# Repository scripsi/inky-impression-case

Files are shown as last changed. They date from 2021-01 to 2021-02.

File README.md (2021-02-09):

# Inky Impression Case

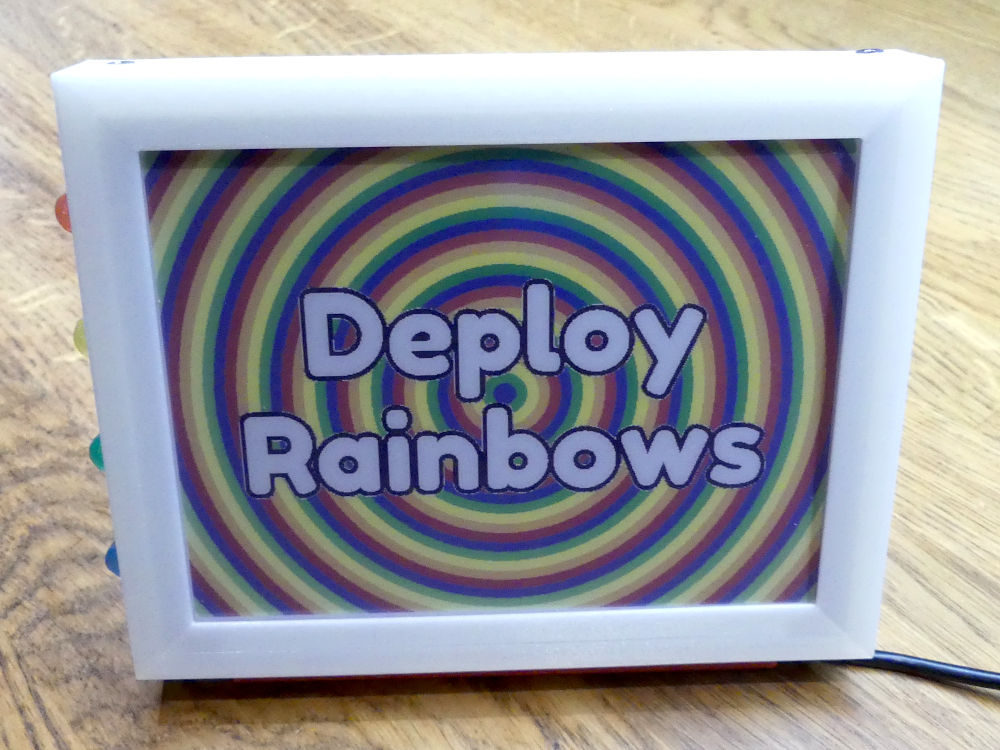
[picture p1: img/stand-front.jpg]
Case on stand - Front

## Introduction

This is a wall-mounting or desk-stand case for the [Pimoroni Inky Impression](https://shop.pimoroni.com/products/inky-impression) 7-colour e-ink display. I wanted to make a simple protective case for the display and a Raspberry Pi Zero W which had the following features:

* A clean front with no visible fixings and a symmetrical border around the image area
* No pressure applied to the fragile glass screen of the Inky Impression
* Access to the 4 buttons on the Inky Impression board
* Access to the breakout connector on the Inky Impression board
* Simple wall-mounting
* An optional desk-stand

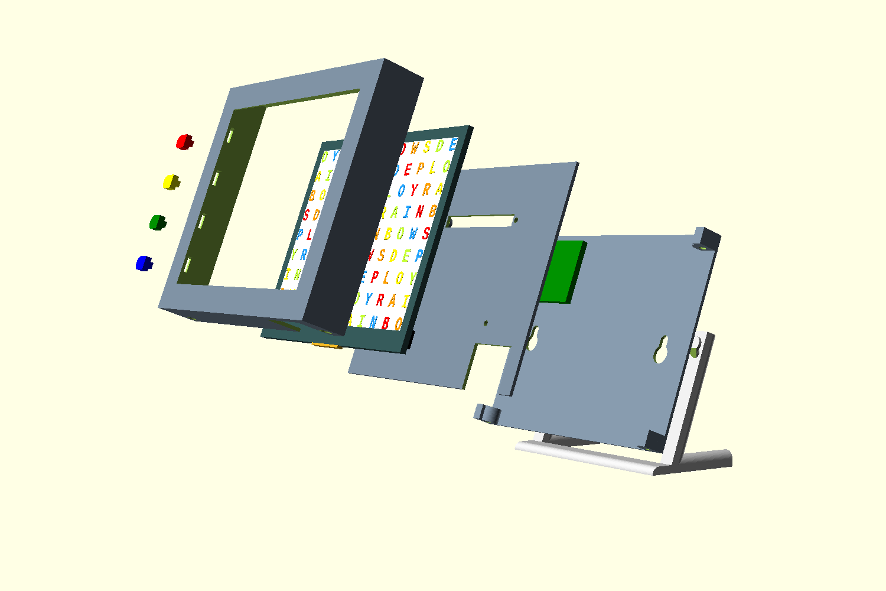
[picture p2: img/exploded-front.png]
Exploded Front View


The Inky Impression only has mounting points on the back surface, which makes it hard to produce a standard, 3d-printable case that doesn't put any pressure on the fragile glass front. Pressing it into a frame or sliding it into slots might put too much strain on some areas. I solved this by adding a backplane within the case, which screws to the Inky Impression's mount points and holds it slightly away from the front of the case.

Side-mounted buttons are also held in position by the backplane and help activate the switches on the Inky Impression board when it is in the case. The rear panel has keyholes for wall-mounting on screws, and is held onto the front of the case by 4 bolts (with optional threaded inserts). The case has a cutout at the bottom for access to the breakout connector and as a cable-exit for the Raspberry Pi's power cable.

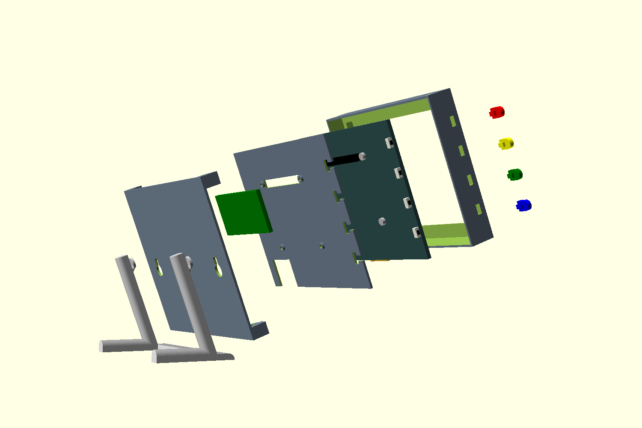
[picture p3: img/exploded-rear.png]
Exploded Rear View


## Printing

Print the following parts:

* 1 x inky-impression-case-frame.stl
* 1 x inky-impression-case-backplane.stl
* 4 x inky-impression-case-button.stl

And, depending on whether or not you are using threaded inserts, either:

* 1 x inky-impression-case-rearpanel.stl (with inserts)

or:

* 1 x inky-impression-case-rearpanel-no-inserts.stl (without inserts)

There is also an optional stand that clips into the keyholes on the rear panel:

* [OPTIONAL: 1 x inky-impression-case-stand.stl]

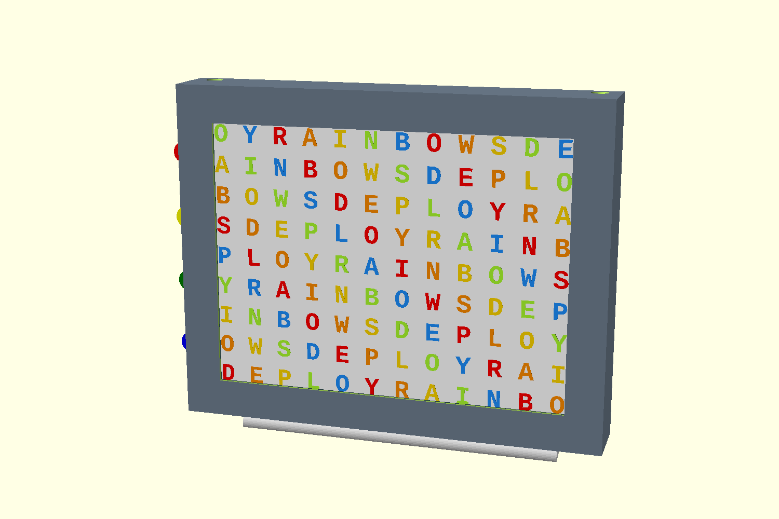
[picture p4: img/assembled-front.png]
Front View


The design is optimised for a 0.4mm nozzle and 0.2mm layer height with 20% infill. Using a concentric pattern on the bottom layer gives a nice finish to the frame.

You will also need:

* 4 x M2.5 bolts, 6mm long (you can use the ones supplied with the Inky Impression)
* 4 x M2.5 countersunk bolts, 6mm long
* [OPTIONAL: 4 x M2.5 threaded inserts - brass heat-set type, external diameter 3.5mm, length 4-6mm]

## Construction

1. Test that the backplane fits right down into the frame to rest on the ledges around the top and sides. It should be a really snug fit - sandpaper the edges of the backplane a bit if it won't go in on the first try!
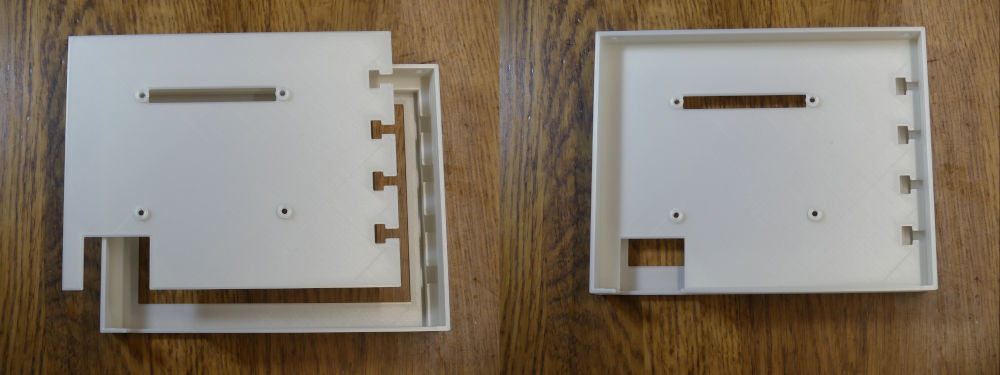
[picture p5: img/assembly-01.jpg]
Assembly - stage 1

2. Mount the backplane to the Inky Impression using the M2.5 bolts that are supplied with the display.
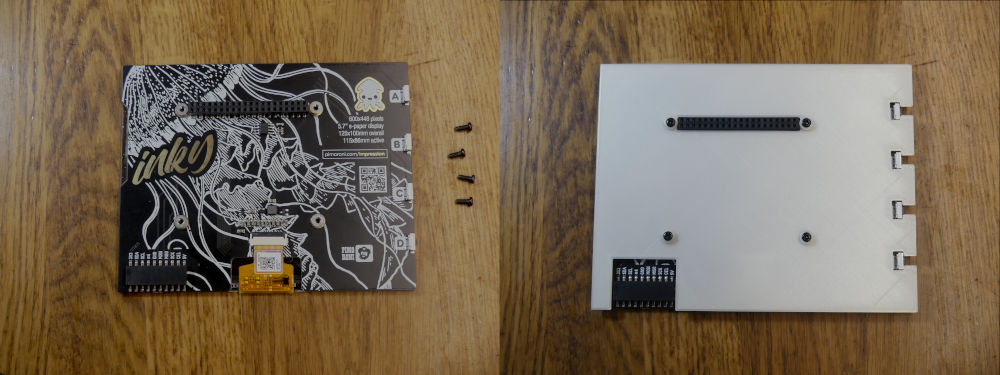
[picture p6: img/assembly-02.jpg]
Assembly - stage 2

3. Lay the frame face down on a worksurface and slide the four buttons into the slots in the side, with the rectangular lugs on each button facing towards you.
4. Gently slide the Inky Impression on its backplane into the frame, with the screen facing down and the slots for the buttons on the correct side.
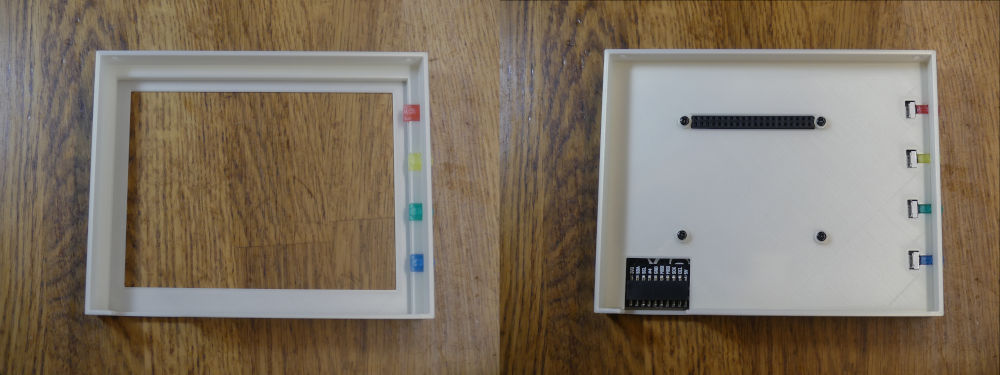
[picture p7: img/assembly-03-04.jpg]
Assembly - stages 3 and 4

5. Carefully press the Raspberry Pi Zero onto the header on the Inky Impression so that it is held firmly in place. Attach a Micro USB cable to the connector nearest the corner of the Pi and lead the cable through the slot in the bottom of the frame.
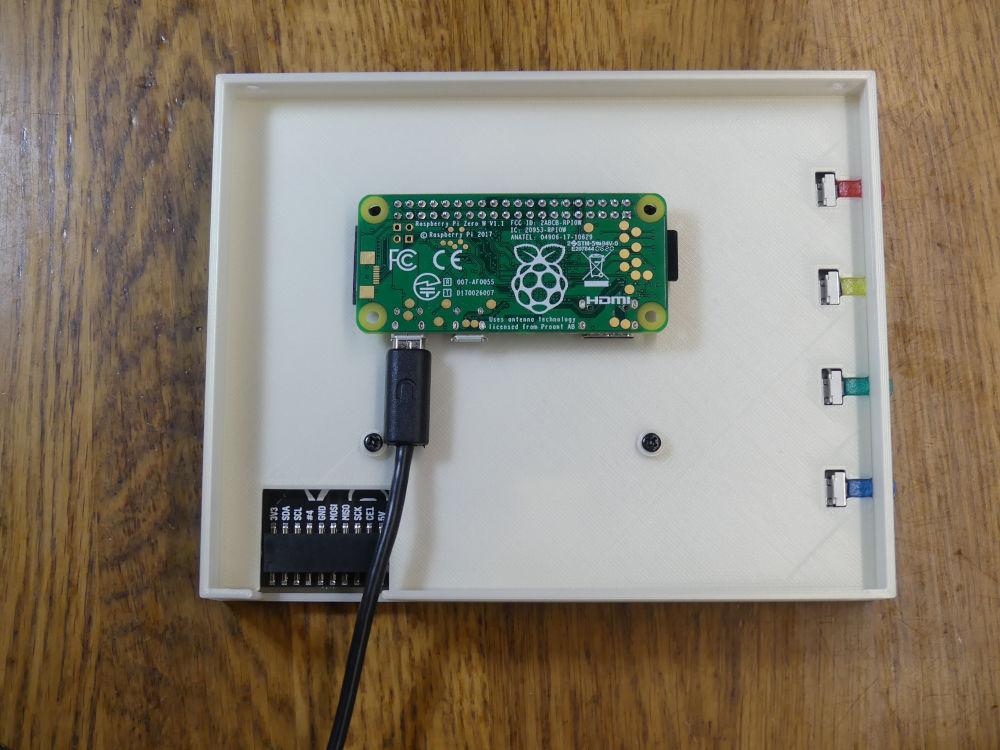
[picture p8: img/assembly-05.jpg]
Assembly - stage 5

6. [Heat-set the inserts](https://markforged.com/resources/blog/heat-set-inserts) (if using) into the mounts on the rear panel.
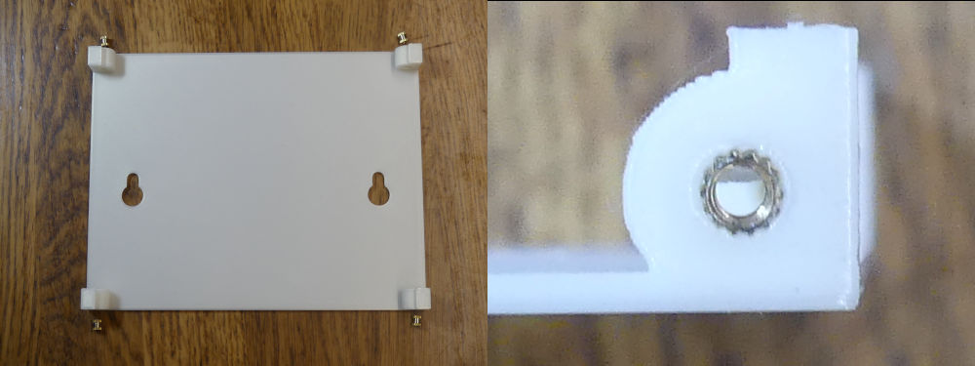
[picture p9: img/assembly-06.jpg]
Assembly - stage 6

7. Place the rear panel into the frame. The pads on the rear panel mounts should hold the backplane in place within the case. Use the M2.5 countersunk bolts to secure the rear panel to the case.
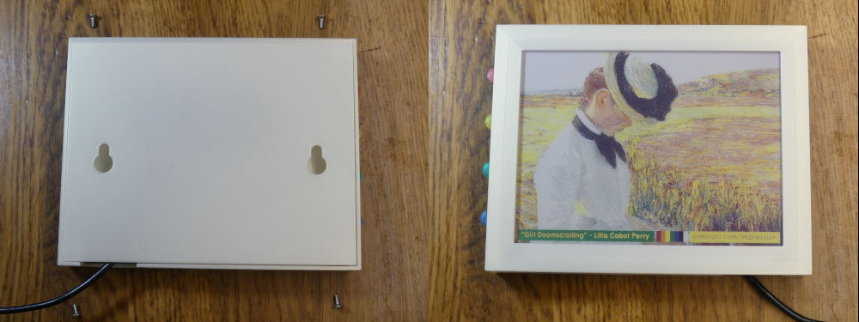
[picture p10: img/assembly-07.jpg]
Assembly - stage 7

8. To wall-mount, place two screws on the wall, 100mm apart and horizontally in line with where you want the centre of the screen, then slot the keyholes in the rear panel onto the screws.

## Customisation

I have included the OpenScad file for the design. It has some basic parameters that allow you to change the size and type of the fixing bolts for the case. Read the comments in the file to see how to use it.

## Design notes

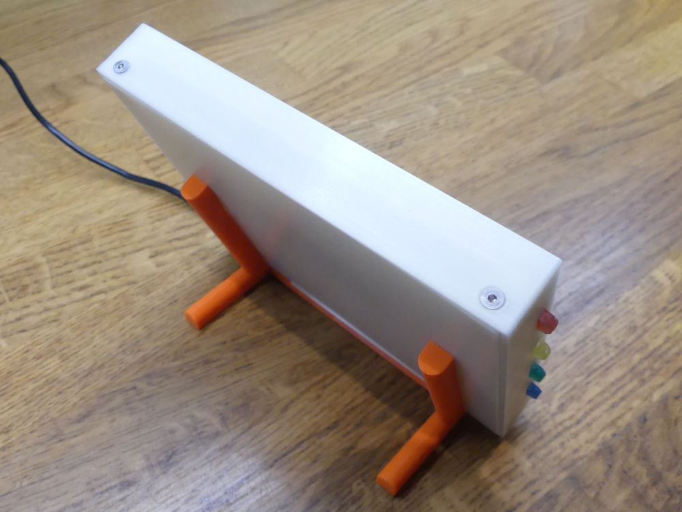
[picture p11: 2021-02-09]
img/stand-rear.jpg

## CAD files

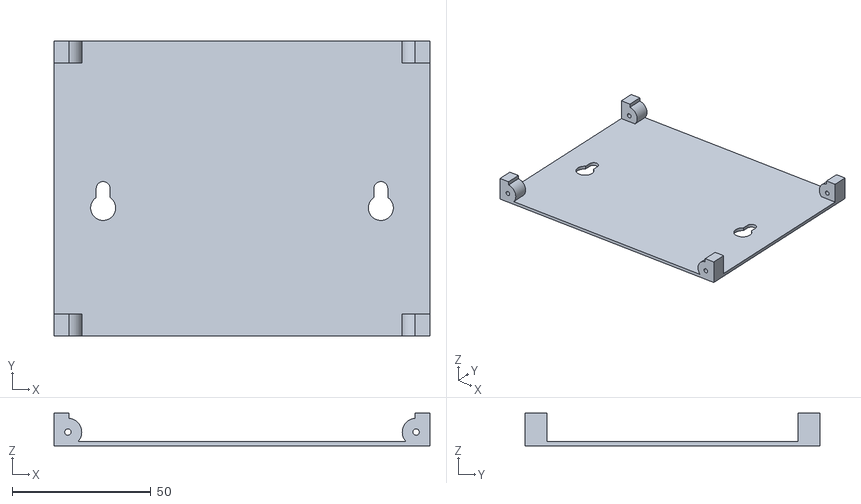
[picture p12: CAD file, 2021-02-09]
inky-impression-case-rearpanel-no-inserts.stl
135.4 x 106.4 x 11.8

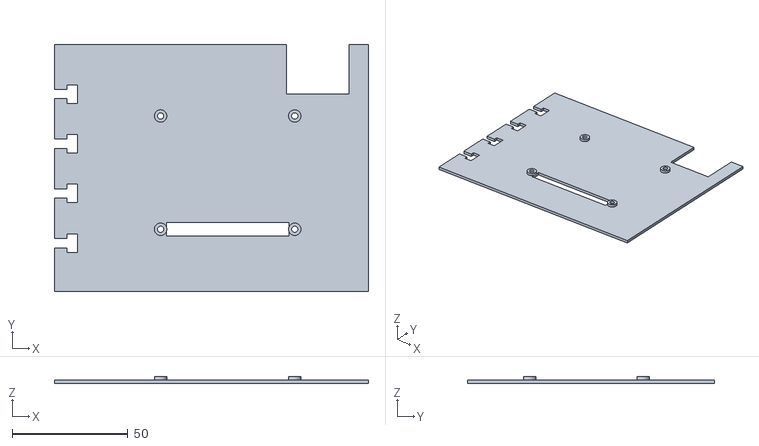
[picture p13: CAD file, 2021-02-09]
inky-impression-case-backplane.stl
135.8 x 106.8 x 3.10

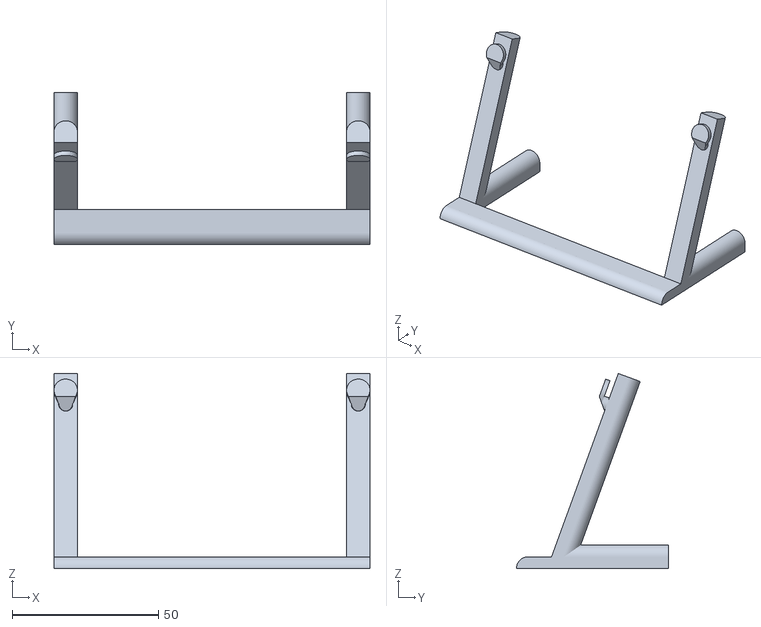
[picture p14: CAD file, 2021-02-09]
inky-impression-case-stand.stl
108.0 x 52.0 x 66.6

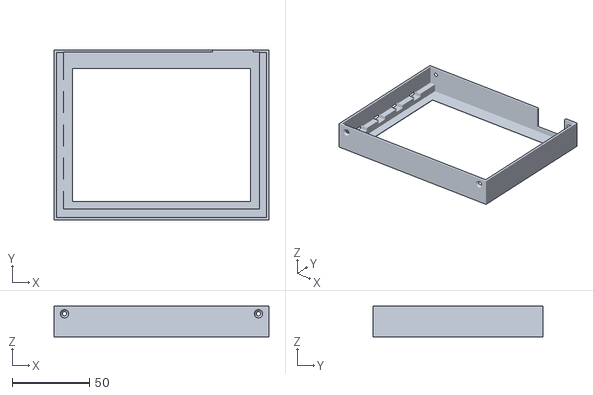
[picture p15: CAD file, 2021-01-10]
inky-impression-case-frame.stl
139.0 x 110.0 x 20.0

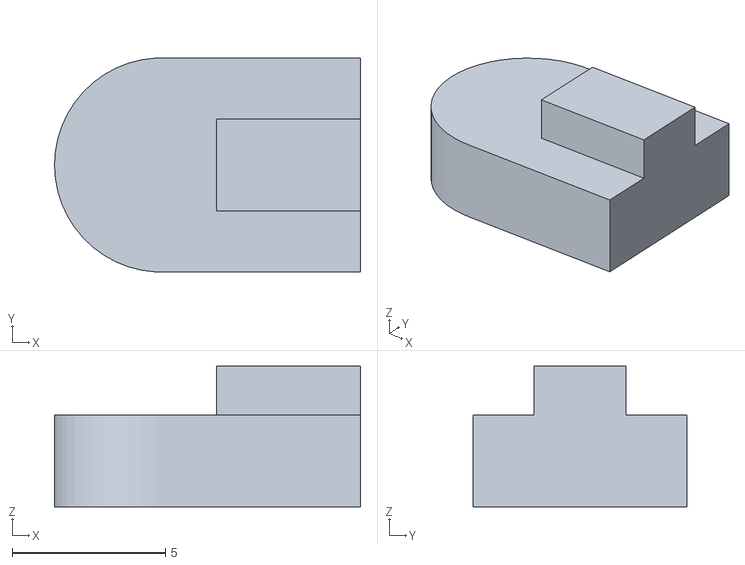
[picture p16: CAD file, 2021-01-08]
inky-impression-case-button.stl
10.0 x 7.00 x 4.60

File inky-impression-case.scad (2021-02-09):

// inky-impression-case.scad
//
// Copyright: Douglas Reed, January 2021
//
// This is a wall-mounting case for:
//
//   Pimoroni Inky Impression 7-colour e-ink display
//   https://shop.pimoroni.com/products/inky-impression
//
// See accompanying readme.md for full details

// The case consists of the following parts:
//
//   1 x FRAME - The front and sides of the case
//   1 x REARPANEL - The rear panel and wall-mount
//   1 x BACKPLANE - An internal panel to hold the Inky Impression in position
//   4 x BUTTON - Button extensions to allow operation of the Inky Impression's
//                buttons
//
// There is also an optional addition:
//
//   1 x STAND - A desk stand that clips into the wall-mount keyholes
//               on the rear panel

// Use the customizer in OpenScad (Menu: Window -> Customizer) to set the
// following parameters and show different parts or views of the model. Only set
// one of these to "true" at a time, and keep the others "false"!

// The frame in printable orientation.
FRAME = false;

// The backplane in printable orientation.
BACKPLANE = false;

// The rear panel in printable orientation.
REARPANEL = false;

// A button in printable orientation
BUTTON = false;

// A desk stand in printable orientation
STAND = false;

// Show the fully assembled case
ASSEMBLED = false;

// Show an exploded view of the case
EXPLODED = false;

// The rear panel is held on by fixing bolts. Set the following parameters 
// According to the bolts you are using

// The diameter of the rear panel fixing bolts
BOLT_DIAMETER = 2.5; // M2.5 bolts

// Countersunk fixing bolts
BOLT_COUNTERSUNK = true;

// The rear panel mounts can take heat-set threaded inserts to make it easier to
// screw in the bolts. Set the following parameter to the recommended hole
// diameter for the inserts you are using (max: 6). If you don't want to
// use inserts and just want to self-tap the bolts into the plastic, set
// this to slightly less than the diameter of the bolts you are using,
// for example: 2.3 for M2.5 bolts

// Threaded insert outer diameter
INSERT_DIAMETER = 3.5;

// Other editable parameters are at the end of the file!

// *** MAIN ROUTINE ***

if (ASSEMBLED) {
  // shows the case fully assembled with Inky Impression and Raspberry Pi Zero
  // boards in position. Prefix any of the lines below with "*" to temporarily
  // remove that element and see inside the case
  frame();
  rearpanel();
  backplane();
  buttons();
  stand();
  inky();
  rpizero();
} else
if (EXPLODED) {
  rotate([-stand_angle,0,0]) {
    translate([0,-50,0]) frame();
    translate([0,130,0]) rearpanel();
    translate([0,150,0]) stand();
    translate([0,50,0]) backplane();
    translate([-50,-50,0]) buttons();
    inky();
    translate([0,80,0]) rpizero();
  }
} else {
  // shows case parts in the correct orientation for printing
  if (FRAME) { rotate([90,0,0]) frame(); }
  if (REARPANEL) { rotate([-90,0,0]) rearpanel(); }
  if (BACKPLANE) { rotate([90,0,0]) backplane(); }
  if (BUTTON) { rotate([90,0,0]) button(0); }
  if (STAND) { rotate([-stand_angle,0,0]) stand(); }
}


// *** MODULES ***

module frame() {
  // The front and sides of the case
  difference() {
    union() { // union of solids
      translate([frame_offset_w,frame_offset_d,frame_offset_h])
        color("SlateGray") cube([frame_w,frame_d,frame_h]);
    } // union of solids
    
    union() { // union of holes
      // screen cutout
      translate([inky_screen_offset_w, frame_offset_d - a_bit, inky_screen_offset_h])
        cube([inky_screen_w, frame_thickness_front + a_bit_more, inky_screen_h]);
      // inky board cutout
      translate([-frame_clearance_w, frame_offset_d + frame_thickness_front, -inky_screen_cable_h - frame_clearance_h])
        cube([inky_board_w + frame_clearance_w * 2, frame_d, inky_board_h+inky_screen_cable_h + frame_clearance_h]);
      // backplane ledge cutout
      translate([frame_offset_w + frame_thickness_sides, backplane_offset_d, frame_offset_h+frame_thickness_sides])
        cube([frame_w - (frame_thickness_sides * 2), frame_d, frame_h - (frame_thickness_sides * 2)]);

      // inky connector cutout
      translate([inky_conn_offset_w, inky_board_d, frame_offset_h - a_bit])
        cube([inky_conn_w, frame_d, frame_thickness_sides + a_bit_more]);
      
      // mount holes
      translate([rearpanel_offset_w, rearpanel_offset_d - rearpanel_mount_d, frame_offset_h]) {
        translate([rearpanel_mount_r,rearpanel_mount_d-rearpanel_mount_r+rearpanel_d,-a_bit]) bolt(radius=rearpanel_mount_bolt_r + rearpanel_mount_bolt_clearance,length=rearpanel_mount_bolt_length);
      }
      translate([rearpanel_offset_w + rearpanel_w - rearpanel_mount_w, rearpanel_offset_d - rearpanel_mount_d, frame_offset_h]) {
        translate([rearpanel_mount_w-rearpanel_mount_r,rearpanel_mount_d-rearpanel_mount_r+rearpanel_d,-a_bit]) bolt(radius=rearpanel_mount_bolt_r + rearpanel_mount_bolt_clearance,length=rearpanel_mount_bolt_length);
      }
      translate([rearpanel_offset_w + rearpanel_w - rearpanel_mount_w, rearpanel_offset_d - rearpanel_mount_d, frame_offset_h + frame_h]) {
        translate([rearpanel_mount_w-rearpanel_mount_r,rearpanel_mount_d-rearpanel_mount_r+rearpanel_d,a_bit]) rotate([180,0,0]) bolt(radius=rearpanel_mount_bolt_r + rearpanel_mount_bolt_clearance,length=rearpanel_mount_bolt_length);
      }
      translate([rearpanel_offset_w, rearpanel_offset_d - rearpanel_mount_d, frame_offset_h + frame_h]) {
        translate([rearpanel_mount_r,rearpanel_mount_d-rearpanel_mount_r+rearpanel_d,a_bit]) rotate([180,0,0]) bolt(radius=rearpanel_mount_bolt_r + rearpanel_mount_bolt_clearance,length=rearpanel_mount_bolt_length);
      }
      
      // buttons
      translate([-frame_border - a_bit, inky_board_d, inky_btn_a_offset_h - button_clearance])
        cube([frame_border + a_bit_more, button_d + button_clearance * 2 , button_h + button_clearance * 2]);
      translate([-frame_border - a_bit, inky_board_d, inky_btn_b_offset_h - button_clearance])
        cube([frame_border + a_bit_more, button_d + button_clearance * 2 , button_h + button_clearance * 2]);
      translate([-frame_border - a_bit, inky_board_d, inky_btn_c_offset_h - button_clearance])
        cube([frame_border + a_bit_more, button_d + button_clearance * 2 , button_h + button_clearance * 2]);
      translate([-frame_border - a_bit, inky_board_d, inky_btn_d_offset_h - button_clearance])
        cube([frame_border + a_bit_more, button_d + button_clearance * 2 , button_h + button_clearance * 2]);
    } // union of holes
  }
} // module frame()
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

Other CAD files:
inky-impression-case-rearpanel.stl

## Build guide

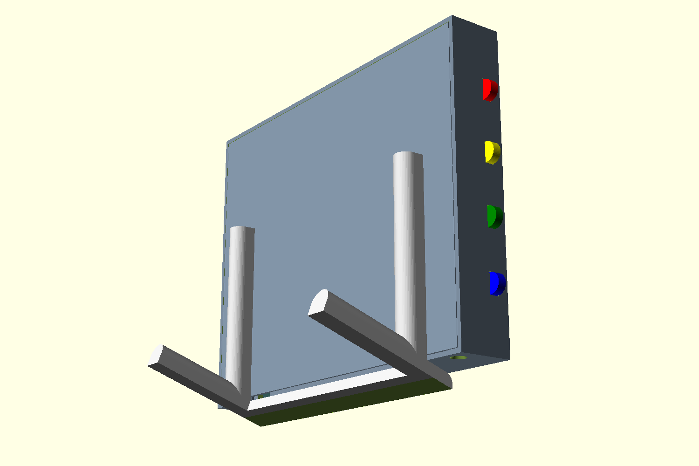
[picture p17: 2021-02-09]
img/assembled-rear.png

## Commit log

2021-01-07 added gitignore to leave out 3mf files
    [inky-impression-case-rearpanel.3mf]
2021-01-07 added version of rearpanel without inserts
    [inky-impression-case-backplane-no-inserts.stl, inky-impression-case-backplane.stl, inky-impression-case-button.stl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]
2021-01-07 fixed filenames
    [inky-impression-case-backplane-no-inserts.stl, inky-impression-case-rearpanel-no-inserts.stl, inky-impression-case-rearpanel.stl]
2021-01-08 Added images and build script
    [inky-impression-case-backplane.stl, inky-impression-case-button.stl, inky-impression-case-frame.stl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]
2021-01-08 Added exploded views
    [inky-impression-case-backplane.stl, inky-impression-case-frame.stl, inky-impression-case-rearpanel-no-inserts.stl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]
2021-01-09 added bolts and countersunk mount holes
    [inky-impression-case.scad]
2021-01-10 added countersunk bolts and increased clearance around inky
    [inky-impression-case-backplane.stl, inky-impression-case-frame.stl, inky-impression-case-rearpanel-no-inserts.stl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]
2021-01-10 Added risers to backplane mounts
    [inky-impression-case-backplane.stl, inky-impression-case-frame.stl, inky-impression-case-rearpanel-no-inserts.stl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]
2021-01-11 fixed incorrect insert size
    [inky-impression-case-backplane.stl, inky-impression-case-button.stl, inky-impression-case-rearpanel-no-inserts.stl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]
2021-02-01 initial branch commit
    [inky-impression-case.scad]
2021-02-03 stand prototype tested
    [inky-impression-case.scad]
2021-02-04 Moved crossbar to increase stability
    [inky-impression-case.scad]
2021-02-09 Created new exploded views
    [inky-impression-case-backplane.stl, inky-impression-case-button.stl, inky-impression-case-frame.stl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]
